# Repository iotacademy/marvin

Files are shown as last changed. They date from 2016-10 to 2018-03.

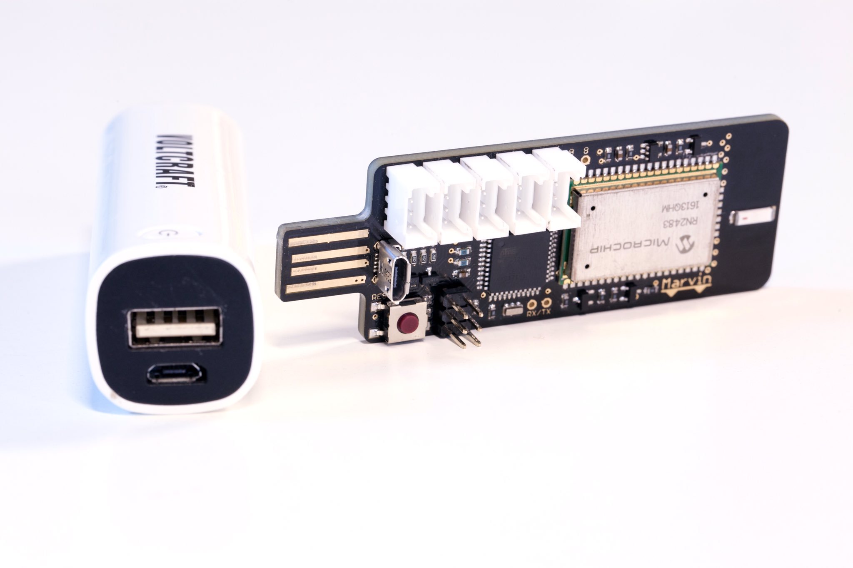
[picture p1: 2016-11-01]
Hardware/Pictures/Marvin_white.jpg

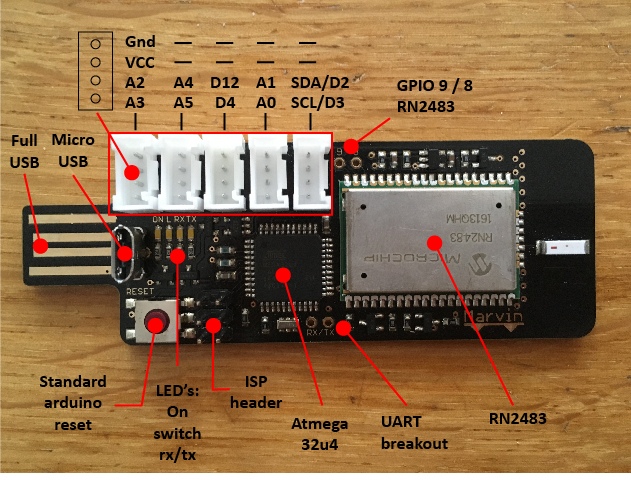
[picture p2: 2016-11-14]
Software/Pictures/Pinout.jpg

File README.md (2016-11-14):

# Marvin

##Hi!!!!

Hello there! Cool of you to made your way here! The whole Marvin team is very excited and welcomes everyone (including you!) to join us in developing awesome/funny/usefull/insightfull or complete bonkers useless gadgets in the world of IoT.

Marvin

##About Marvin

Marvin is easy to use, Arduino based, plug and play grove sensor compatible and works with LoRa communication on the KPN nation covering LoRa network.

Please check our [Kickstarter campaign](https://www.kickstarter.com/projects/688158475/marvin-the-lora-development-board/), the possibilities at the [IoTAcademy](http://iotacademy.nl) and the [RDM Makerspace](http://www.rdmmakerspace.nl/cursussen/internet-of-things).

##What are you doing here?!

Okay that may have come of a bit harsh. We *do* welcome you, but you are kinda on a junction here.

Are you interested in:

[Software](https://github.com/iotacademy/marvin/tree/master/Software)?

or 

[Hardware](https://github.com/iotacademy/marvin/tree/master/Hardware)?

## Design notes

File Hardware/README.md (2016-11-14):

# Marvin Hardware
This overview contains documentation regarding the hardware used in Marvin. 

##General
The Marvin consists of 4 main features: A USB port, Arduino compatible microcontroller, 5 Grove connectors and a LoRa(WAN) modem. The board is optimized to be used for quick and easy applications in R&D and workshops, as well as a very reasonable solution for embedded applications.

##ATMEGA32u4

ATMEGA32u4

##Grove connectors
The 5 grove connectors cover all analog(x3), digital(x1) and I2C(x1). The I2C port can also be used as a digital input/output.

Grove connectors

##ISP
The 2x3 male header is used to burn the bootloader on the microcontroller. As this is done via SPI, this bus is available for other SPI peripherals. On the bottom there are an additional 6 contact pads using pogo pins instead of a 2x3 wired connector.

ISP header

##Serial
The RX/TX pins from the microcontroller are available via an unpopulated connection. The LoRa modem is controlled over the same line, so it needs to be shut down when other UART devices are used to prevent errors.

##GPIO
Next to the Grove connectors there is another two unpopulated connection point, connected to GPIO 8 and 9 of the LoRa module.

GPIO

##Antenna
The antenna is a 868MHz ceramic resonator antenna with a pigtail behind it. The choice to go for a ceramic antenna (instead of the regular antenna on SMA connector that is spec'd) was done for two reasons, the on-pcb ceramic antenna is a lot smaller and less fragile, and in our side-by-side tests the ceramic antenna performed considerably better on all scores.

Antenna

##USB
The full size USB plug and the micro USB are linked directly together. The full size connector is used for plugging it right in your laptop, the micro USB can be used when the unit is embedded in a place where is not easily removeable and makes the system a lot more flexible.

##Level shifters
The microcontroller and the LoRa modem work at different voltages (5v&3.3V), so for the communication and reset lines there are level shifters in place. 

Level Shifters

##Dimensions
The overal dimensions of the PCB are 85x30mm and the pcb is 2.4mm thick. This thickness is required to make the PCB fit the usb port.

Dimensions

##Board and Schematics
See Layout folder.

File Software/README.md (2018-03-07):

# Marvin
Essentials for Marvin LoRa Development

Marvin Plug&Play app: https://dent.mendixcloud.com.
10 week free trial, afterwards free use on demand

Hookup guide: http://www.dentgalaxy.com/marvin/resources-nl/

Enjoy!

## Getting started

### Install Arduino IDE

Download the [Arduino IDE](https://www.arduino.cc/en/Main/Software) and follow the installer. 

If you want to donate to Arduino -to help developing their software we are thankfully using- this is possible, but not mandatory.

### Connect Marvin to computer

Use your left or right (or a combination) hand to push the Marvin in the USB port of your computer. Your computer will quickly befriend it and say "blingBLING", which is computer language for "we are now BFFs!".

Plugged in

### Upload Blinky

Download (or copy-paste the contents of) [Blinky.ino](https://github.com/iotacademy/marvin/blob/master/Software/MarvinBlink/MarvinBlink.ino) and open it in the Arduino IDE.

From the 'Tools' menu select 'Arduino Leonardo' in the 'Boards' section.

Click upload to send the software to the Marvin. If all went well it will say Uploading complete and the second LED will blink, if not try uploading again.

Board selection

Upload sketch

### Check RN2483

Download [MarvinMultiSerial.ino](https://github.com/iotacademy/marvin/blob/master/Software/MarvinMultiSerial/MarvinMultiSerial.ino) and open it in the Arduino IDE.

Upload it to the Marvin and then open the Serial Monitor

Serial Monitor

Set the baudrate to 57600 (same as in the sketch) and select 'CR+NL'. Now you can directly speak to the RN2483 and get a response.

If you for instance send 'sys get ver', the module will return its firmware version back. This will be 1.0.1 with some historic date.

Possible other commands can be find in the module [data sheet](http://ww1.microchip.com/downloads/en/DeviceDoc/40001784E.pdf) or in [one of the many](https://www.disk91.com/2015/technology/networks/first-step-in-lora-land-microchip-rn2483-test/) [examples](https://thinginnovations.uk/getting-started-with-microchip-rn2483-lorawan-modules) [by others](http://kotahi.net/configure-microchip-rn2483-module/).

## Using your first sensor

The Marvin uses Grove sensors. Grove is a standard developed by [Seeedstudio](https://www.seeedstudio.com/category/Grove-c-45.html), a large electronics shop. In their [wiki page](http://wiki.seeedstudio.com/wiki/Main_Page) you can find a quite comprehensive collection of documentation of all products.

### Sensor and connector

The pinout of the Marvin allows for 3 analog sensors, 1 digital and 1 I2C sensor (I2C can also be used as regular digital port). If needed, with a splitter up to 256 I2C can be hooked up though.

Pinout

## Sending message to other Marvin

Upload MarvinMultiSerial to two Marvins

### Listening

On the first Marvin, open serial monitor and type:
```
mac pause 
radio rx 0
```
This will put it in continous listening mode. If it says 'radio_err' it is timed out or received something weird. No worries, just repeat 'radio rx 0' command to restart it.

### Broadcasting

On the second Marvin type:
```
mac pause
radio set pwr 14
radio tx 12345678
```
On the serial monitor of Marvin 1 it should display your message '12345678'.

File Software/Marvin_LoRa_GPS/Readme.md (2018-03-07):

# SETUP YOUR MARVIN + GPS 

## General
The Microchip lora module is connected over UART with the Arduino Leonardo 32u4. Power consumption of the GPS module is around 150 mA.

## Kill power to RN2483
Uart can only handle one master and one slave device. Since GPS is also using UART communcication, you have to kill the power to the RN2483. Do this by writing pin 5 (power RN2483) and pin 6 (reset RN2483) LOW. 

## Connect rx tx pins
Next you connect rx to tx of the gps and tx to rx, using the pads provided on the lower edge of the Marvin (USB pointing to left)

## Use a transistor
To control the power to the GPS, you need an PNP transistor that has the gate connected to one of the arduino's digital pin. 
In active mode, the GPS requires +50mA, which is more then a digital pin of the 32u4 can provide. 
Using a PNP between the VCC of the gps and the VCC of the marvin will allow for enough power to run the gps properly. 
You can use digital pin 12 for this, 3rd grove connector - look on the bottom of the board - to cut off the power. 

In this way, you can retreive gps coordinates, store them in a variable, kill gps power, fire up lora and send variables in the payload. 

Enjoy your gps lora tracker!

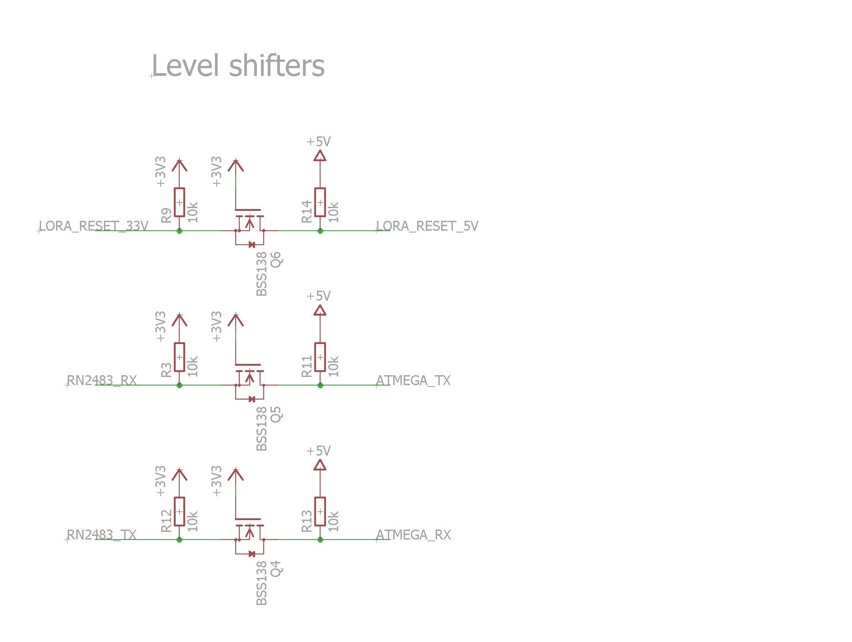
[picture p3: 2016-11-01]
Hardware/Pictures/LevelShifters.JPG

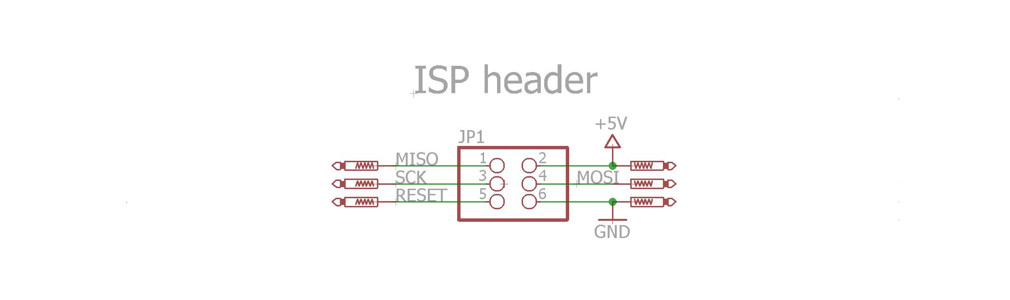
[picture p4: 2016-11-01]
Hardware/Pictures/ISPheader.JPG

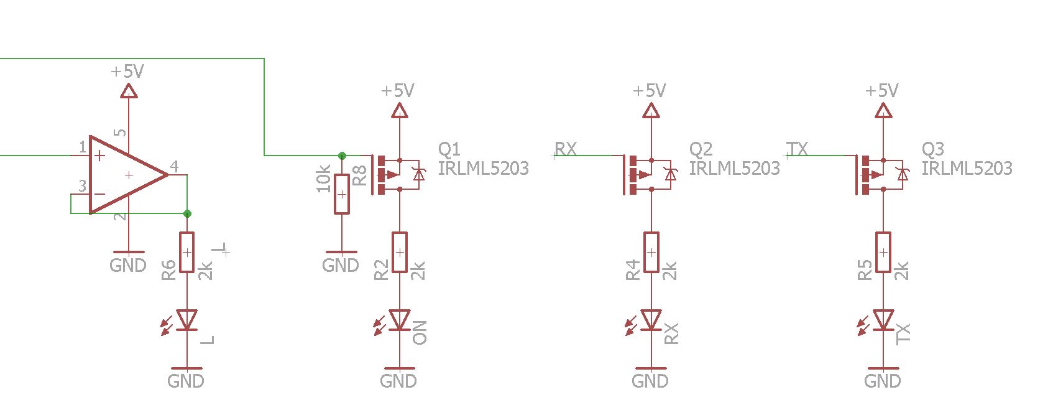
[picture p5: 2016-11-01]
Hardware/Pictures/LEDs.JPG

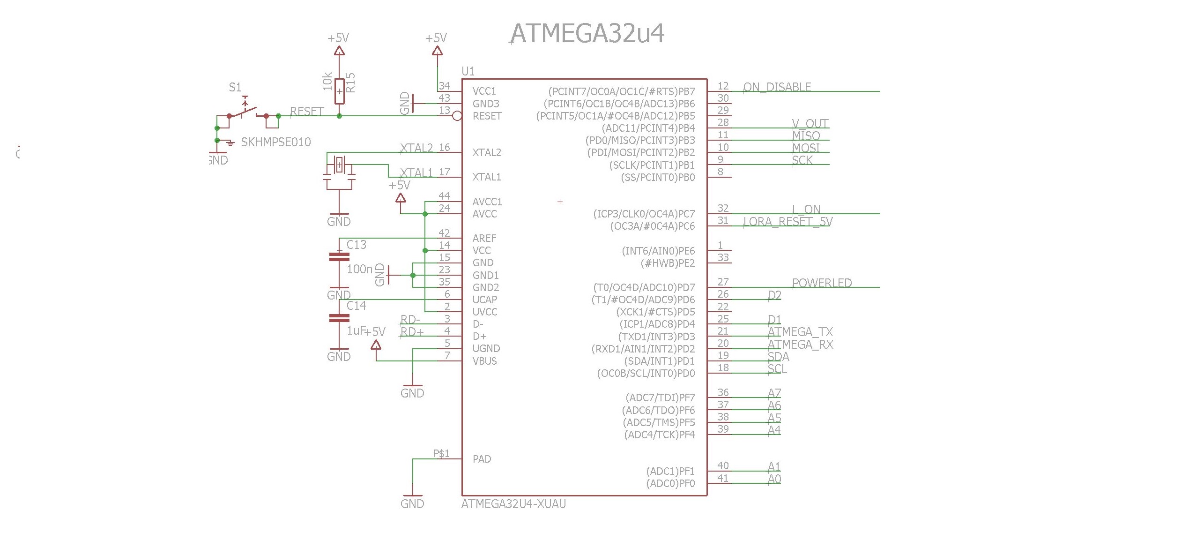
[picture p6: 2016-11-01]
Hardware/Pictures/ATMEGA32u4.JPG

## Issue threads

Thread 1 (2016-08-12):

MarvinMultiSerial doesn't work with arduino SDK 1.6.10

peer23peer, 2016-08-12:

MichielJol, 2016-09-09:
This seems to be true, solution is using Arduino SDK 1.6.9 or 1.6.11

Closed 2016-09-09.

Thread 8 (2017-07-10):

LoRa Arduino UNO

Tonibco, 2017-07-10:
Hi, I would just like to modify Temperature and humidity sketch in order to be able to use it by Arduino 'UNO' Board and LoRa module, rather than 'Mega' one. Since I saw Serial1 port communication is used on this code. So, my question is;

- Which steps should I take in order to modify the code for the purpose I comment above?

Many thanks

overlord1123, 2017-08-04:
I would recommend looking at the wiring in the hardware section. Use Eagle for convenience which is free to download. The hard part is the digital level shifters since Arduino runs on 5V and the module runs at 3.3V.

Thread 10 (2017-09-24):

Seeed GPS Grove Module v1.2 and Marvin

patmolloy, 2017-09-24:
Hi,

I am trying to use this module on the 3rd Marvin Grove Port (Marked D12 and D4 on the bottom of the PCB) in conjunction with the SoftwareSerial library. Here is the start of the sketch. It does not work - SoftSerial.available() always return 0. I have tried swapping the 12,4 around just in case I had RX/TX swapped. In looking at the schematics I am wondering whether that Grove port is really Digital 12 and Digital 4 ?? (seems to suggest D1 and D2).

Assuming I can get the ports right, should this actually work? I cannot see why not!

If I need to use the broken out RX/TX pads on the PCB .. what is the code I need?

Thanks!!

Pat

```
#include <SoftwareSerial.h>
SoftwareSerial SoftSerial(12,4);            // RX, TX
unsigned char buffer[64];                   // buffer array for data receive over serial port
int count=0;                                // counter for buffer array
void setup()
{
    SoftSerial.begin(9600);                 // the SoftSerial baud rate
    Serial.begin(9600);                     // the Serial port of Arduino baud rate.

}

void loop()
{
    Serial.print("Hello --- ");
    Serial.println(SoftSerial.available());
    if (SoftSerial.available())                     // if data is coming from software serial port ==> data is coming from SoftSerial shield
```

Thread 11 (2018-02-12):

Low power mode

ehtick, 2018-02-12:
Can't get the low power mode from the atmega in combination with the RN2483 to work.

I want to create a sampling application which samples at a frequency of 15 minutes.
For this we put the atmega to sleep which works but combined with the RN2483 sys sleep ......  gives hangup's.

What is the correct way to use as little of power possible (SLEEP_MODE_IDLE) in combination with the RN2482 sys sleep command. Now i created a watchdog timer to wakeup again.

ISR(WDT_vect)
{
  sleep_count ++; // keep track of how many sleep cycles
                  // have been completed.
  if (sleep_count == sleep_total)
    Wakeup();          
}

in loop i test that Wakeup has set the volatile int to do action and then sample the data send it and got to sleep again.  Any help is welcome 👍

OlegSomov, 2018-03-08:
Hello @ehtick ,

Is that is what you're looking for? powerDown turns off everything is possible:
```
void loop() {
    LowPower.powerDown(SLEEP_8S, ADC_OFF, BOD_OFF);
    LowPower.powerDown(SLEEP_8S, ADC_OFF, BOD_OFF);

    // Executing some code sending a message.
}
```

ehtick, 2018-03-09:
We use the Lowpower but this does not sleep the RN2483 chip. So after using the LowPower library it still uses about 5-7 mA and this is tho much.

OlegSomov, 2018-03-09:
I just tried to add mac sleep command, and got as low as  1.5-2 mA.. Device is transmitting frames as it supposed to.
```
void loop() {
    send_LoRa_Command("sys sleep 13000");
    LowPower.powerDown(SLEEP_8S, ADC_OFF, BOD_OFF);
    LowPower.powerDown(SLEEP_8S, ADC_OFF, BOD_OFF);

    // Executing some code sending a message.
}
```

Is your device stops transmitting?

ehtick, 2018-03-09:
Yes it stops, engineer at microchip give the advise to set a delay of 150ms after sending 'sys sleep xxxx'

OlegSomov, 2018-03-09:
Hmm.. even without delay I have module working and transmitting constantly combining powerDown and "sys sleep xxxxx". Couple of questions for you:
1. How do you check the transmissions?(if device transmitted or not)
2. Where is device connected to, when you running a code with sleep and powerdown?
3. Do you have any prints to USB serial?

ehtick, 2018-03-09:
1 we always expect a result from the RN2483 so sometimes 'ok', 'accepted'
when sending payload wait for mac_tx_ok. Problem with the sys sleep command is that it sends ok when it wakes up again.
2 We do not run code on powerdown or sleep
3 usb is deactivated and no serial print is used (when debugging yes :))

Updated the firmware for the RN2483 to the latest one, microchip advise, but this does not help.

OlegSomov, 2018-03-09:
1. After the powerDown most of the board peripherals shut down, so you not going to see anything in the debugging port, so when you use powerDown, to check transmission please check the Network Server side.

What is the value you put in "sys sleep ..."?

ehtick, 2018-03-12:
20 minutes so 20 * 60 * 1000 (long)

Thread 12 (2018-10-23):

Marvin LoRa stops after first loop when code WaterFlowSensor is changed with code TemperatureSensor

PannekoekenMetSpinazie, 2018-10-23:
Hi Githubbers,

Today I tried to connect Marvin LoRa device with The Things Network, fortunaly with basic program from https://github.com/iotacademy/marvin/blob/master/Software/MarvinBase/MarvinBase.ino allows me to connect to The Things Network (Keys are changed to the ones I use with TTN).

After I changed the code with temperature sensor to waterflow sensor the code stops running after the first loop. The first reading is send to TTN, but not the following readings because the loop got stuck.

Waterflow sensor is YF-402.
The port used is farthest from the Marvin LoRa USB.
Program: Arduino
Board: Arduino Leonardo

Can you guys explain what has happened to the loops?
The code I use is as follows:

/*
MarvinBase

Basic controls of IoT Academy Marvin LoRa Development board.

This version supports:

Sending LoRa uplink messages using ABP
Blink three times when sending data
Power control to RN2483 module
Instructions:

Get the latest version of the Arduino software
In Arduino IDE select Arduino Leonardo and com port of your device
Please adjust ABP adresses and key below to match yours
The loop() is where the actual stuff happens. Adjust input of send_lora_data() in void loop() to send your own data.
*/
/// #include <CayenneLPP.h> //App integratie

/// CayenneLPP lpp(51); //Buffergrootte in bytes

// Port to assign the type of lora data (any port can be used between 1 and 223)
int set_port = 1;

// Some standard ports that depend on the layout of the Marvin
long defaultBaudRate = 57600;
int reset_port = 5;
int RN2483_power_port = 6; //Note that an earlier version of the Marvin doesn't support seperate power to RN2483
int led_port = 13;

int flowPin = 39; //This is the input pin on the Arduino
float flowRate; //This is the value we intend to calculate.
volatile float count; //This integer needs to be set as volatile to ensure it updates correctly during the interrupt process.

//*** Set parameters here BEGIN ---->
String set_nwkskey = "XXXXXXXXXXXXXXXXXXXXXXXXXXXXXX"; // Make sure you use your keys from TTN here
String set_appskey = "XXXXXXXXXXXXXXXXXXXXXXXXXXXXXX";
String set_devaddr = "XXXXXXXX";
//*** <---- END Set parameters here

/*

Setup() function is called when board is started. Marvin uses a serial connection to talk to your pc and a serial

connection to talk to the RN2483, these are both initialized in seperate functions. Also some Arduino port are

initialized and a LED is called to blink when everything is done.
*/
void setup() {
Serial.begin(defaultBaudRate);
Serial1.begin(defaultBaudRate);
InitializeSerials(defaultBaudRate);
initializeRN2483(RN2483_power_port, reset_port);
pinMode(led_port, OUTPUT); // Initialize LED port
blinky();

pinMode(flowPin, INPUT); //Sets the pin as an input
attachInterrupt(0, Flow, RISING); //Configures interrupt 0 (pin 2 on the Arduino Uno) to run the function "Flow"
Serial.begin(9600); //Start Serial
}

void loop() {

count = 0; // Reset the counter so we start counting from 0 again
interrupts(); //Enables interrupts on the Arduino
delay (1000); //Wait 1 second
noInterrupts(); //Disable the interrupts on the Arduino

//Start the math
flowRate = (count / 4.380); //Take counted pulses in the last second and multiply by 98
flowRate = flowRate * 60; //Convert seconds to minutes, giving you mL / Minute

flowRate = flowRate + 0.5;
int mL_min = (int)flowRate;

Serial.println(mL_min);

delay(100);
send_LoRa_data(set_port, String(mL_min));
blinky();
delay(1000);
read_data_from_LoRa_Mod();
delay(3000);
}

void Flow()
{
count++; //Every time this function is called, increment "count" by 1
}

void InitializeSerials(int baudrate)
{
delay(1000);
print_to_console("Serial ports initialised");
}

void initializeRN2483(int pwr_port, int rst_port)
{
//Enable power to the RN2483
pinMode(pwr_port, OUTPUT);
digitalWrite(pwr_port, HIGH);
print_to_console("RN2483 Powered up");
delay(1000);

//Disable reset pin
pinMode(rst_port, OUTPUT);
digitalWrite(rst_port, HIGH);

//Configure LoRa module
send_LoRa_Command("sys reset");
read_data_from_LoRa_Mod();

send_LoRa_Command("radio set crc off");
delay(1000);
read_data_from_LoRa_Mod();

send_LoRa_Command("mac set nwkskey " + set_nwkskey);
read_data_from_LoRa_Mod();

send_LoRa_Command("mac set appskey " + set_appskey);
read_data_from_LoRa_Mod();

send_LoRa_Command("mac set devaddr " + set_devaddr);
read_data_from_LoRa_Mod();

//For this commands some extra delay is needed.
/// send_LoRa_Command("mac set adr on");
/// delay(1000);
/// read_data_from_LoRa_Mod();

send_LoRa_Command("mac save");
delay(1000);
read_data_from_LoRa_Mod();

send_LoRa_Command("mac join abp");
delay(1000);
read_data_from_LoRa_Mod();

}

void print_to_console(String message)
{
Serial.println(message);
}

void read_data_from_LoRa_Mod()
{
if (Serial1.available()) {
String inByte = Serial1.readString();
Serial.println(inByte);
}

}

void send_LoRa_Command(String cmd)
{
print_to_console("Now sending: " + cmd);
Serial1.println(cmd);
delay(500);
}

void send_LoRa_data(int tx_port, String rawdata)
{
send_LoRa_Command("mac tx uncnf " + String(tx_port) + String(" ") + rawdata);
}

void blinky()
{
digitalWrite(led_port, HIGH); // turn the LED on (HIGH is the voltage level)
delay(500); // wait for a second
digitalWrite(led_port, LOW); // turn the LED off by making the voltage LOW
delay(500); // wait for a second
digitalWrite(led_port, HIGH); // turn the LED on (HIGH is the voltage level)
delay(500); // wait for a second
digitalWrite(led_port, LOW); // turn the LED off by making the voltage LOW
delay(500); // wait for a second

}

Closed 2018-10-24.

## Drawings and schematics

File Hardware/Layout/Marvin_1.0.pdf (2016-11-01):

# Level shifters

# SKHMPSE010 ⁺³V3 10k

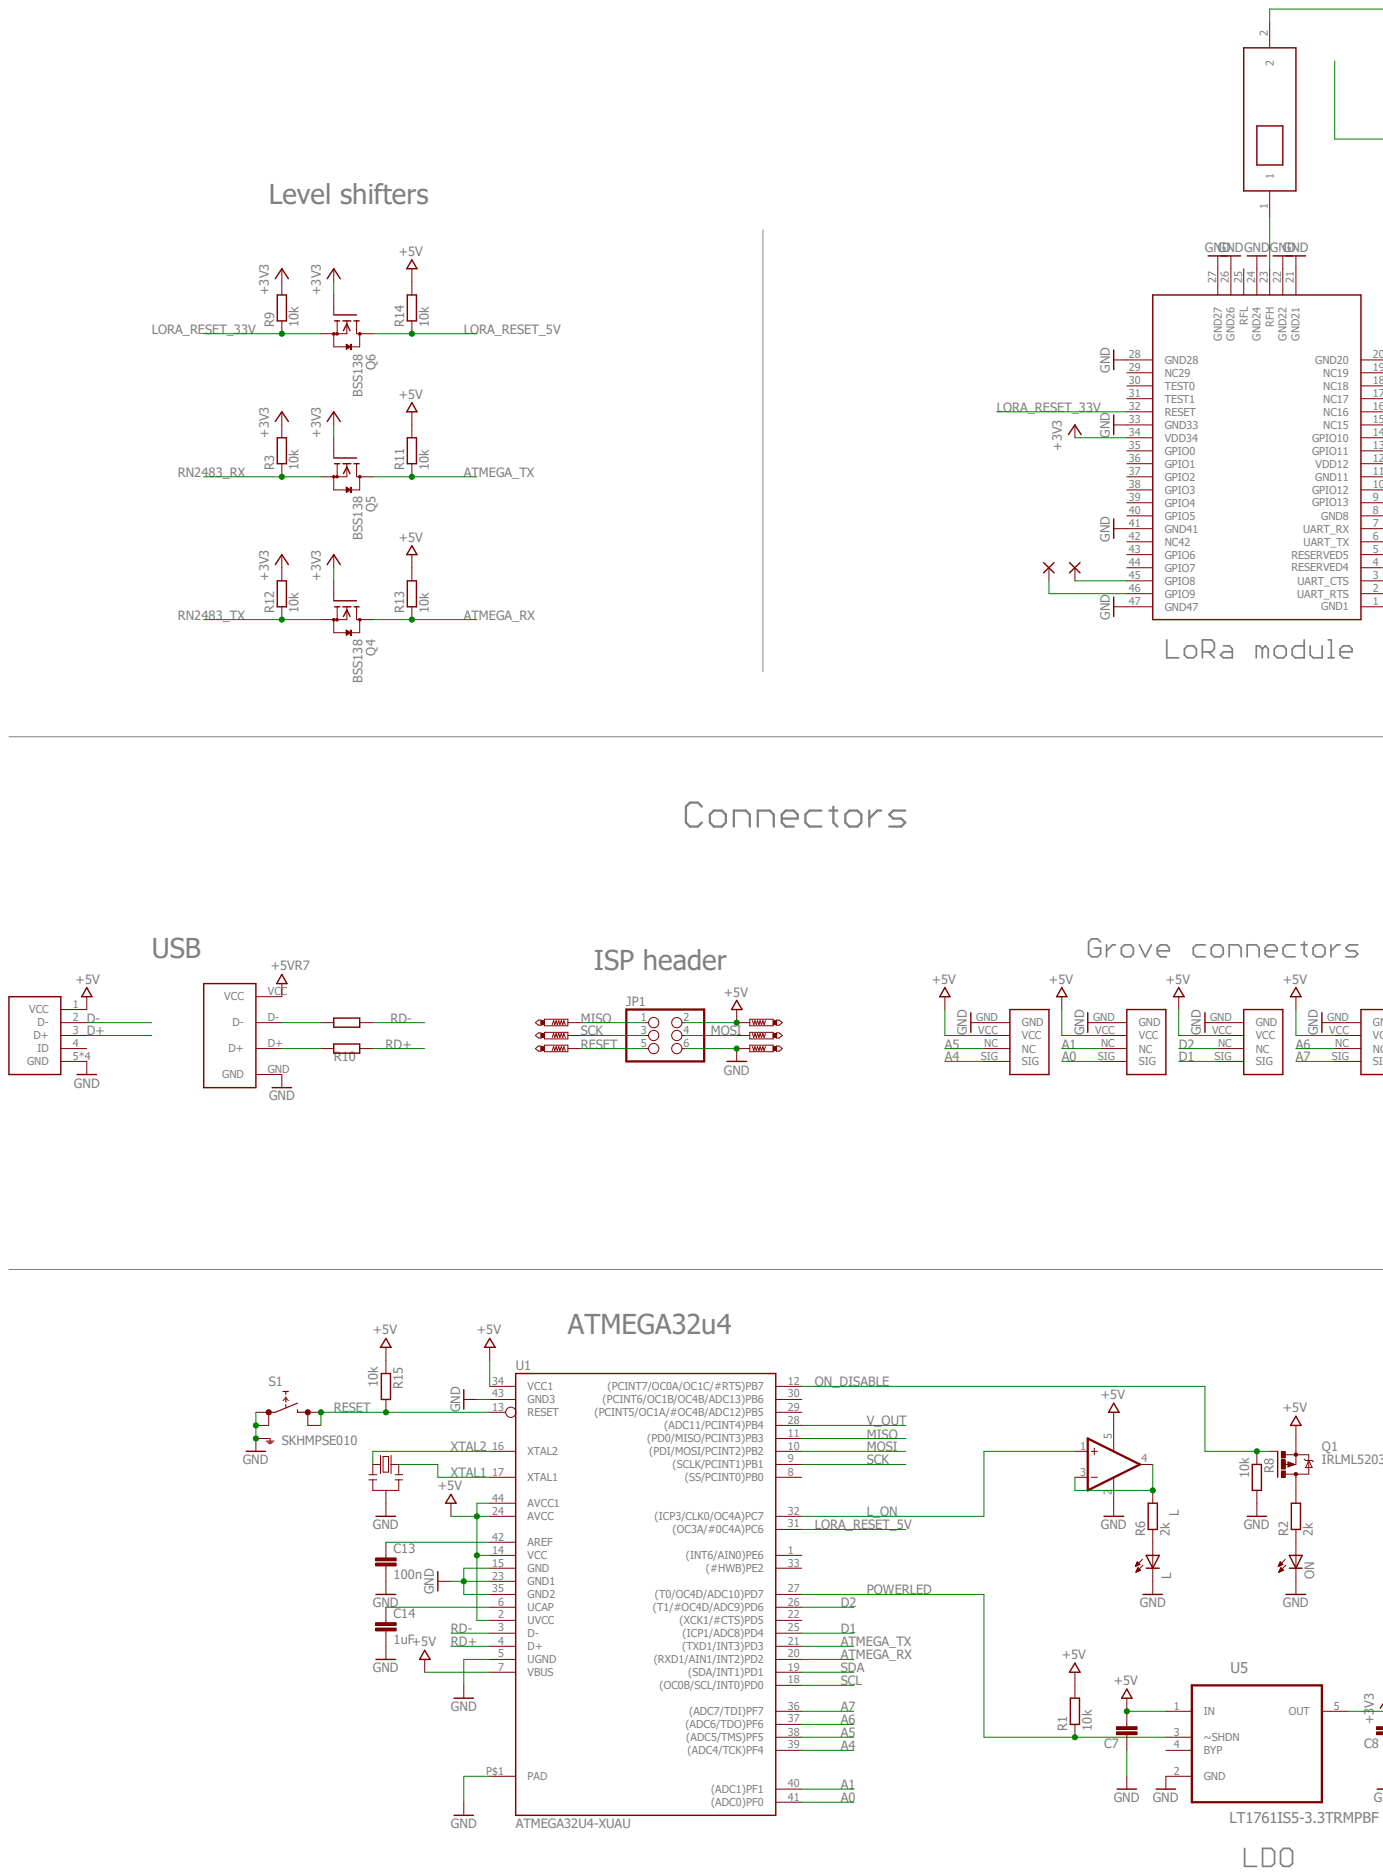
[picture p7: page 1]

VCC 14

GND1 23

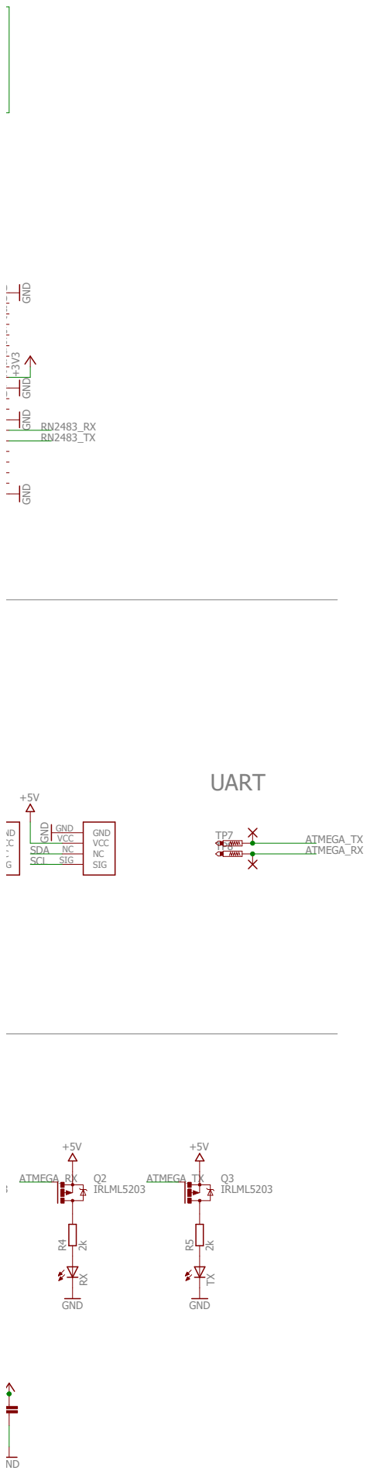
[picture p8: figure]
UART; GND GND GND GND; GND; GND ²k; IRLML5203; VCC VCC; SIG SIG; GND GND; ATMEGA_RX; SDA SCL; ATMEGA_TX

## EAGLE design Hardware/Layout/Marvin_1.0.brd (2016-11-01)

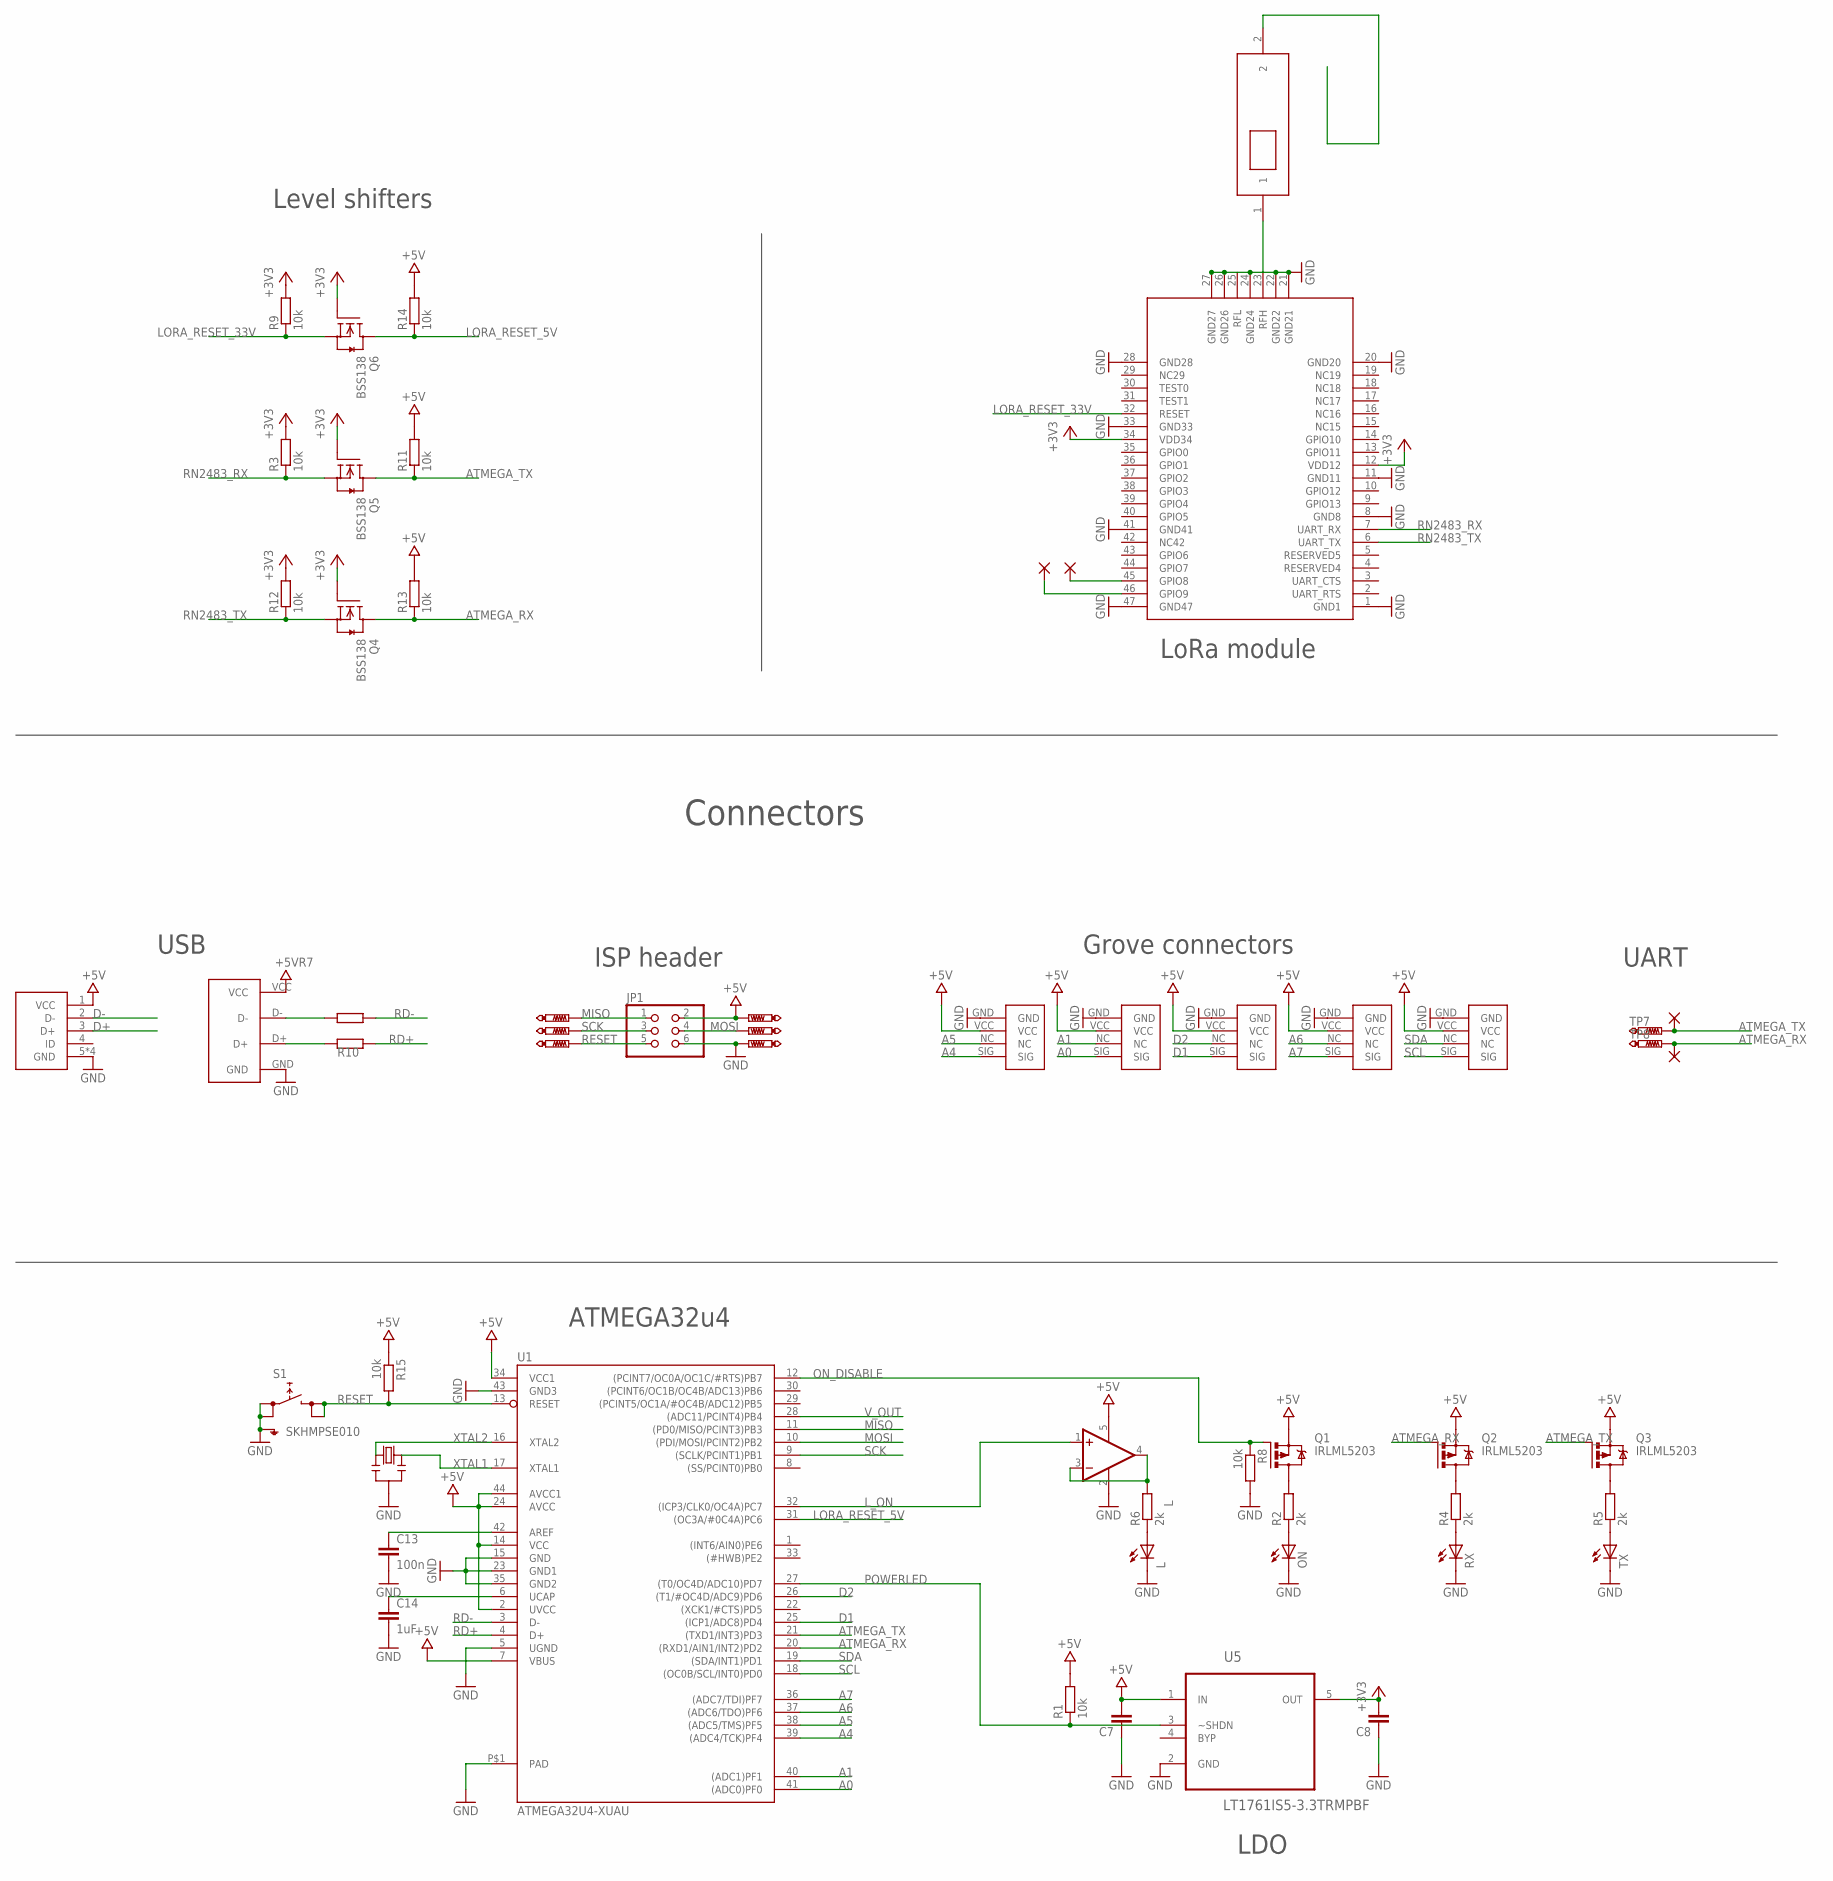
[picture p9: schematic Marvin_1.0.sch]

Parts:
A1, A2, A3: GROVE; 4POS2MM
C7, C8: C-EUC0603; C0603
C13: 100n; C0603K
C14: 1uF; C0603K
D2, D2/I2C: GROVE; 4POS2MM
IC1: LM321MF; SOT23-5
JP1: PINHD-2X3; 2X03
L: LEDSML0603; SML0603
ON: LEDSML0603; SML0603
PAD1, PAD2, PAD3, PAD4: WIREPAD1,6/0,9; 1,6/0,9
Q1, Q2, Q3: IRLML5203; MICRO3
Q4, Q5, Q6: BSS138; SOT23
R1, R3, R8, R9, R11, R12, R13, R14, R15: 10k; R0603
R2, R4, R5, R6: 2k; R0603
R7, R10: 30; R0603-ROUND
RX: LEDSML0603; SML0603
S1: SKHMPSE010; SKHMPXE010
TP1, TP2, TP3, TP4, TP5, TP6, TP7, TP8: PTR1B1,27; B1,27
TX: LEDSML0603; SML0603
U1: ATMEGA32U4-XUAU; TQFP44-PAD
U5: LT1761IS5-3.3TRMPBF; SOT95P280X100-5N
U$1: RN2483
U$3: USBA; USBAPLUG
U$16: USB-VERTICAL; MICROUSBVERTICAL
U$25: 868AT
Y1: CSTCE16M0V53-R0 16MHZ; RESONATOR

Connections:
+3V3: C8.2, Q4.1 (G), Q5.1 (G), Q6.1 (G), R3.2, R9.2, R12.2, U5.5 (OUT), U$1.12 (VDD12), U$1.34 (VDD34)
+5V: A1.VCC, A2.VCC, A3.VCC, C7.2, D2.VCC, D2/I2C.VCC, IC1.5 (V+), JP1.2, Q1.2 (S), Q2.2 (S), Q3.2 (S), R1.2, R11.2, R13.2, R14.2, R15.1, TP6.TP, U1.2 (UVCC), U1.7 (VBUS), U1.14 (VCC), U1.24 (AVCC), U1.34 (VCC1), U1.44 (AVCC1), U5.1 (IN), U$3.VCC, U$16.1 (VCC)
A0: A1.SIG, U1.41 ((ADC0)PF0)
A1: A1.NC, U1.40 ((ADC1)PF1)
A4: A2.SIG, U1.39 ((ADC4/TCK)PF4)
A5: A2.NC, U1.38 ((ADC5/TMS)PF5)
A6: A3.NC, U1.37 ((ADC6/TDO)PF6)
A7: A3.SIG, U1.36 ((ADC7/TDI)PF7)
AREF1: C13.1, U1.42 (AREF)
ATMEGA_RX: PAD2.1, Q2.1 (G), Q4.3 (D), R13.1, TP8.TP, U1.20 ((RXD1/AIN1/INT2)PD2)
ATMEGA_TX: PAD1.1, Q3.1 (G), Q5.3 (D), R11.1, TP7.TP, U1.21 ((TXD1/INT3)PD3)
D1: D2.SIG, U1.25 ((ICP1/ADC8)PD4)
D2: D2.NC, U1.26 ((T1/#OC4D/ADC9)PD6)
D+: R10.2, U$3.D+, U$16.3 (D+)
D-: R7.2, U$3.D-, U$16.2 (D-)
GND: A1.GND, A2.GND, A3.GND, C7.1, C8.1, C13.2, C14.2, D2.GND, D2/I2C.GND, IC1.2 (V-), JP1.6, L.C, ON.C, R8.2, RX.C, S1.1 (1.1), S1.2 (1.2), S1.5 (SH), TP4.TP, TX.C, U1.5 (UGND), U1.15 (GND), U1.23 (GND1), U1.35 (GND2), U1.43 (GND3), U1.P$1 (PAD), U5.2 (GND), U$1.1 (GND1), U$1.8 (GND8), U$1.11 (GND11), U$1.20 (GND20), U$1.21 (GND21), U$1.22 (GND22), U$1.24 (GND24), U$1.26 (GND26), U$1.27 (GND27), U$1.28 (GND28), U$1.33 (GND33), U$1.41 (GND41), U$1.47 (GND47), U$3.GND, U$16.5 (GND), U$16.P$1 (GND), U$16.P$2 (GND), U$16.P$3 (GND), Y1.2
L: IC1.3 (-IN), IC1.4 (OUT), R6.2
LORA_RESET_5V: Q6.3 (D), R14.1, U1.31 ((OC3A/#0C4A)PC6)
LORA_RESET_33V: Q6.2 (S), R9.1, U$1.32 (RESET)
L_ON: IC1.1 (+IN), U1.32 ((ICP3/CLK0/OC4A)PC7)
MISO: JP1.1, TP1.TP, U1.11 ((PD0/MISO/PCINT3)PB3)
MOSI: JP1.4, TP5.TP, U1.10 ((PDI/MOSI/PCINT2)PB2)
unnamed: ON.A, R2.1
unnamed: R4.1, RX.A
unnamed: R5.1, TX.A
unnamed: L.A, R6.1
unnamed: Q1.3 (D), R2.2
unnamed: PAD3.1, U$1.46 (GPIO9)
unnamed: Q2.3 (D), R4.2
unnamed: Q3.3 (D), R5.2
unnamed: PAD4.1, U$1.45 (GPIO8)
ON_DISABLE: Q1.1 (G), R8.1, U1.12 ((PCINT7/OC0A/OC1C/#RTS)PB7)
POWERLED: R1.1, U1.27 ((T0/OC4D/ADC10)PD7), U5.3 (~SHDN)
RD+: R10.1, U1.4 (D+)
RD-: R7.1, U1.3 (D-)
RESET: JP1.5, R15.2, S1.3 (2.1), S1.4 (2.2), TP3.TP, U1.13 (RESET)
RFH: U$1.23 (RFH), U$25.1
RN2483_RX: Q5.2 (S), R3.1, U$1.7 (UART_RX)
RN2483_TX: Q4.2 (S), R12.1, U$1.6 (UART_TX)
SCK: JP1.3, TP2.TP, U1.9 ((SCLK/PCINT1)PB1)
SCL: D2/I2C.SIG, U1.18 ((OC0B/SCL/INT0)PD0)
SDA: D2/I2C.NC, U1.19 ((SDA/INT1)PD1)
UCAP: C14.1, U1.6 (UCAP)
V_OUT: U1.28 ((ADC11/PCINT4)PB4)
XTAL1: U1.17 (XTAL1), Y1.3
XTAL2: U1.16 (XTAL2), Y1.1

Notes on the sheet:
Grove connectors
LoRa module
LDO
USB
Level shifters
ATMEGA32u4
ISP header
UART
Connectors

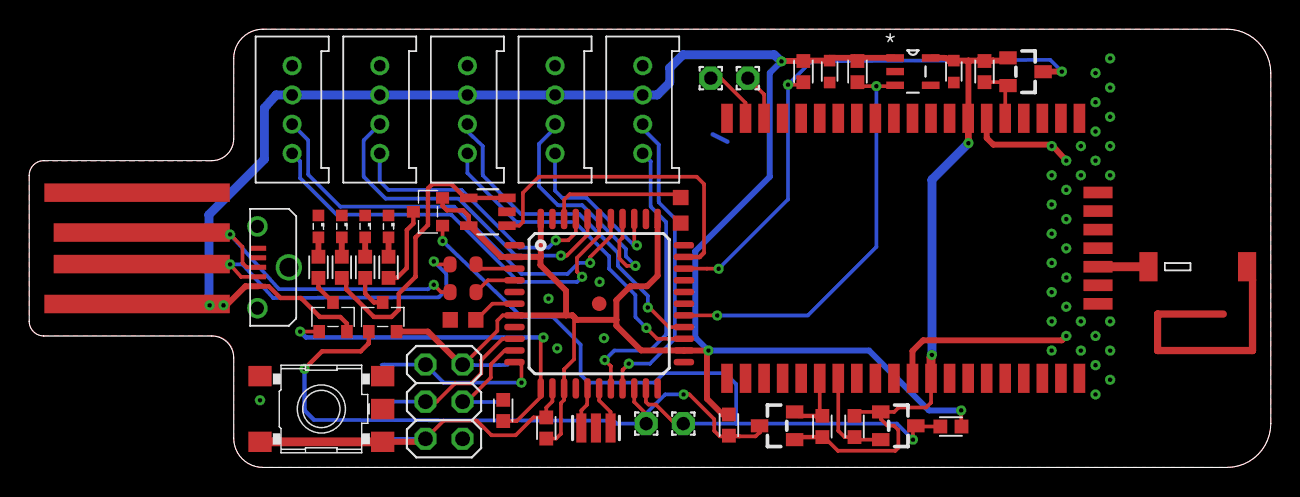
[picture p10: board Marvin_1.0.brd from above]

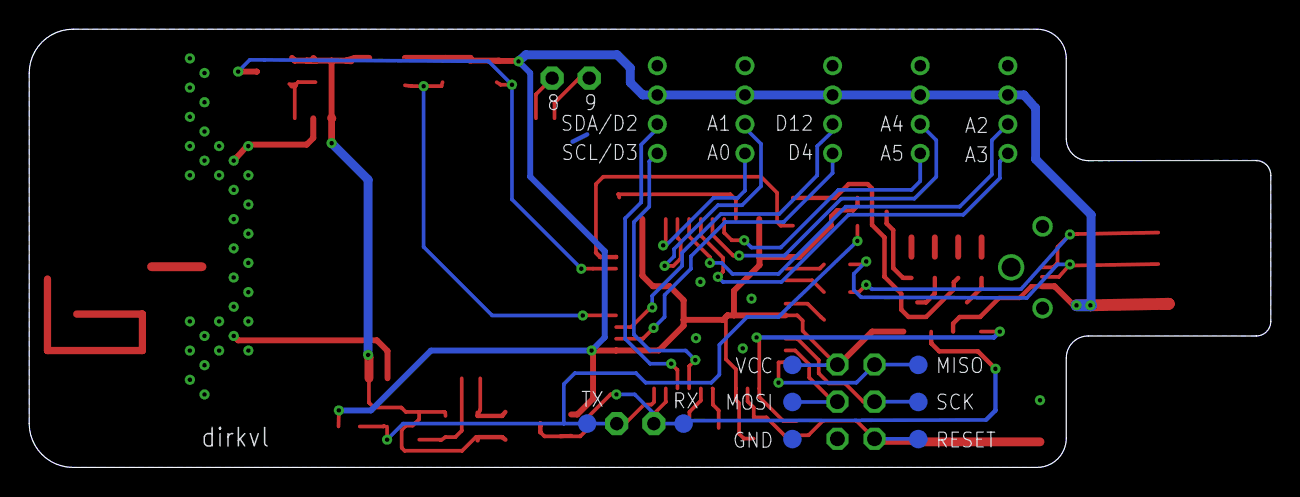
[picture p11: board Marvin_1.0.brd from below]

Board: 2 copper layers, 85.0 x 30.0 mm, 56 parts (8 on the bottom side), 45 nets.

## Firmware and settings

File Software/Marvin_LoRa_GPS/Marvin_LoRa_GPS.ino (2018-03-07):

/*
  Marvin_LoRa_GPS + Button
  
  Connect the gps using a grove - female jumper wire:
  - GND to any GND
  - VCC to Collector pin of PNP transistor
  - RX  to TX - located on the lower edge of the board. 
  - TX to RX - locataed on the lower edge of the board.
  
  For the pnp transistor:
  - Connect Collector pin to VCC GPS
  - Connect Emitter pin to VCC from ISP header
  - Connect gate pin to D12

  This version supports:
  - Sending LoRa uplink messages using ABP that are given as input from the serial port on your laptop
  - Blink three times when sending data
  - Power control to RN2483 module

  Instructions:
  - Get the latest version of the Arduino software
  - In Arduino IDE select Arduino Leonardo and com port of your device
  - Please adjust ABP adresses and key below to match yours
  - Download tinypgs++ library and import it in your arduino IDE: Sketch > Include library > add .zip library
*/
// Port to assign the type of lora data (any port can be used between 1 and 223)
int     set_port  = 1;

// Some standard ports that depend on the layout of the Marvin
long    defaultBaudRate = 9600;
long    newBaudRate = 57600;
int     reset_port = 5;
int     RN2903_power_port = 6;
int     led_port = 13;
int     buttonstate = A3;
int     gps_pwr = 3;
float   latti;
float   longi;
int     counter = 0;
int     powerstategps = 0;
int     waarde;


//*** Set parameters here BEGIN ---->
String  set_nwkskey = "xxxxxxxxxxxxxxxxxxxxxxxxxxxxxxxx"; // Put your 32 hex char here
String  set_appskey = "xxxxxxxxxxxxxxxxxxxxxxxxxxxxxxxx"; // Put your 32 hex char here
String  set_devaddr = "xxxxxxxx"; // Put your 8 hex char here
//*** <---- END Set parameters here

// Some global items
String reader = "";
#include <TinyGPS++.h>  //you will have to download+install the tinygps++ library, just google it, first hit.
#include <math.h>
TinyGPSPlus gps;


void setup()
{
  pinMode(gps_pwr, OUTPUT);
  pinMode(buttonstate, INPUT);
  digitalWrite(gps_pwr, LOW);
  initializeRN2903(RN2903_power_port, reset_port);
  delay(100);
  Serial.println("Hello There, Let's go!");
  pinMode(led_port, OUTPUT); // Initialize LED port
  blinky();
}

void loop(){

// This program assumes you use a button on the A3 port. Each button press the program below will run. 

  if (digitalRead(buttonstate) == 1 && powerstategps == 0){
      restartRN2903(RN2903_power_port, reset_port);
      send_LoRa_Command("mac tx uncnf " + String(set_port) + String(" ") + 01);                 //send confirmation message
      delay(1000);
      read_data_from_LoRa_Mod();
      blinky();
      delay(1000);
      Serial.println("Zeroing in on your location, just a sec...");      //start gps tracking
      killRN2903(RN2903_power_port, reset_port);                                                //kill rn module for uart
      delay(100);
      digitalWrite(gps_pwr, HIGH);                                                              //start gps on port gps_pwr
      powerstategps = 1;                                                                        //write variable to indicate gps is on
      print_to_console("GPS Powered up");
  }
  
   if (digitalRead(buttonstate) == 1 && powerstategps == 1){
      digitalWrite(gps_pwr, LOW);
      print_to_console("GPS Killed!");
      powerstategps = 0;
      delay(2000);
   }
  
  if (digitalRead(gps_pwr) == HIGH){
        printFloat(gps.location.lat(), gps.location.isValid(), 11, 6);                        //start printing values - will return stars as long as there is no valid location
        printFloat(gps.location.lng(), gps.location.isValid(), 12, 6);
        Serial.println(" ");
        smartDelay(1000);

        if (millis() > 5000 && gps.charsProcessed() < 10) {
            Serial.println(F("No GPS data received: check wiring"));
            blinky_error();
        }
  
        if(gps.location.isValid() == true && gps.location.isUpdated() == true){
                    digitalWrite(13, HIGH);

                    latti = gps.location.lat();
                    longi = gps.location.lng();        
                    uint32_t  n = latti * 1000000;
                    uint32_t  e = longi * 1000000;
                    Serial.println(n);
                    Serial.println(e);  
                    blinky_error();
                    digitalWrite(gps_pwr, LOW); //kill gps
                    powerstategps = 0;
                    Serial.println("GPS KILLED");
                    Serial.println("sending gps now");
                    
                    restartRN2903(RN2903_power_port, reset_port);
                    digitalWrite(led_port, HIGH);
                    send_LoRa_Command("mac tx uncnf " + String(set_port) + String(" ") + String(n) + String(e));
                    delay(1000);
                    read_data_from_LoRa_Mod();
                    blinky();
                    delay(1000);
                    killRN2903(RN2903_power_port, reset_port);
                    digitalWrite(led_port, LOW);
                    
        }
    }
// go back to main loop again and wait for gps to become true
}


//Lora part --------------------------------------------

void InitializeSerials(long baudrate)
{
  Serial.flush ();   // wait for send buffer to empty
  delay (100);    // let last character be sent
  Serial1.flush ();   // wait for send buffer to empty
  delay (100);    // let last character be sent
  Serial.end ();
  Serial1.end ();
  delay(100);
  Serial.begin(baudrate);
  Serial1.begin(baudrate);
  delay(100);
  print_to_console("Serial ports initialised");
}

void initializeRN2903(int pwr_port, int rst_port)
{
  //Enable power to the RN2903
  InitializeSerials(newBaudRate);
  delay(1000);
  pinMode(pwr_port, OUTPUT);
  digitalWrite(pwr_port, HIGH);
  delay(1000);
  print_to_console("RN2903 Powered up");

  //Disable reset pin
  pinMode(rst_port, OUTPUT);
  digitalWrite(rst_port, HIGH);

  //Configure LoRa module
  send_LoRa_Command("sys reset");
  read_data_from_LoRa_Mod();

  send_LoRa_Command("mac set nwkskey " + set_nwkskey);
  read_data_from_LoRa_Mod();

  send_LoRa_Command("mac set appskey " + set_appskey);
  read_data_from_LoRa_Mod();

  send_LoRa_Command("mac set devaddr " + set_devaddr);
  read_data_from_LoRa_Mod();

  //For this commands some extra delay is needed.
  send_LoRa_Command("mac set adr on");
  //send_LoRa_Command("mac set dr 0"); //uncomment this line to fix the RN2903 on SF12 (dr=DataRate)
  read_data_from_LoRa_Mod();

  send_LoRa_Command("mac save");
  delay(1000);
  read_data_from_LoRa_Mod();

}

void killRN2903(int pwr_port, int rst_port)
{
  //disable power to the RN2903
 // pinMode(pwr_port, OUTPUT);
 // digitalWrite(pwr_port, LOW);
  //Disable reset pin
  pinMode(rst_port, OUTPUT);
  digitalWrite(rst_port, LOW);
  print_to_console("RN2903 killed");
  delay(1000);
  InitializeSerials(defaultBaudRate);
}

void restartRN2903(int pwr_port, int rst_port)
{
  //Enable power to the RN2903
  InitializeSerials(newBaudRate);
  delay(1000);
  //Disable reset pin
  pinMode(rst_port, OUTPUT);
  digitalWrite(rst_port, HIGH);
  pinMode(pwr_port, OUTPUT);
  digitalWrite(pwr_port, HIGH);
  delay(1000);
  print_to_console("RN2903 repowered up");
  
  send_LoRa_Command("mac join abp");
  delay(1000);
  read_data_from_LoRa_Mod();
  send_LoRa_Command("radio set crc off");
  delay(1000);
  read_data_from_LoRa_Mod();
  delay(100);
}

void print_to_console(String message)
{
  Serial.println(message);
}

void read_data_from_LoRa_Mod()
{
  if (Serial1.available()) {
    String inByte = Serial1.readString();
    delay(100);
    Serial.println(inByte);
  }

}

void send_LoRa_Command(String cmd)
{
  print_to_console("Now sending: " + cmd);
  Serial1.println(cmd);
  delay(500);
}

void send_LoRa_data(int tx_port, String rawdata)
{
  send_LoRa_Command("mac tx uncnf " + String(tx_port) + String(" ") + rawdata);
  delay(100);
}


void blinky()
{
  digitalWrite(led_port, HIGH);   // turn the LED on (HIGH is the voltage level)
  delay(500);              // wait for a second
  digitalWrite(led_port, LOW);    // turn the LED off by making the voltage LOW
  delay(500);              // wait for a second
  digitalWrite(led_port, HIGH);   // turn the LED on (HIGH is the voltage level)
  delay(500);              // wait for a second
  digitalWrite(led_port, LOW);    // turn the LED off by making the voltage LOW
  delay(500);              // wait for a second

}
void blinky_error()
{
  digitalWrite(led_port, HIGH);   // turn the LED on (HIGH is the voltage level)
  delay(50);              // wait for a second
  digitalWrite(led_port, LOW);    // turn the LED off by making the voltage LOW
  delay(50);              // wait for a second
  digitalWrite(led_port, HIGH);   // turn the LED on (HIGH is the voltage level)
  delay(50);              // wait for a second
  digitalWrite(led_port, LOW);    // turn the LED off by making the voltage LOW
  delay(50);              // wait for a second
  digitalWrite(led_port, HIGH);   // turn the LED on (HIGH is the voltage level)
  delay(50);              // wait for a second
  digitalWrite(led_port, LOW);    // turn the LED off by making the voltage LOW
  delay(50);              // wait for a second
  digitalWrite(led_port, HIGH);   // turn the LED on (HIGH is the voltage level)
  delay(50);              // wait for a second
  digitalWrite(led_port, LOW);    // turn the LED off by making the voltage LOW
  delay(50);              // wait for a second

}
//---------------------end lora part

// This custom version of delay() ensures that the gps object
// is being "fed".
static void smartDelay(unsigned long ms)
{
  unsigned long start = millis();
  do
  {
    while (Serial1.available())
      gps.encode(Serial1.read());
  } while (millis() - start < ms);
}

static void printFloat(float val, bool valid, int len, int prec)
{
  if (!valid)
  {
    while (len-- > 1)
      Serial.print('*');
    Serial.print(' ');
  }
  else
  {
    Serial.print(val, prec);
    int vi = abs((int)val);
    int flen = prec + (val < 0.0 ? 2 : 1); // . and -
    flen += vi >= 1000 ? 4 : vi >= 100 ? 3 : vi >= 10 ? 2 : 1;
    for (int i = flen; i < len; ++i)
      Serial.print(' ');
  }
  smartDelay(0);
}

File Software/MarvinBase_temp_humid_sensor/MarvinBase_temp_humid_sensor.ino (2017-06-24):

/*
MarvinBase

Basic controls of IoT Academy Marvin LoRa Development board.

This version supports:
	- Sending LoRa uplink messages using ABP 
	- Blink three times when sending data
  - Power control to RN2483 module

Instructions:
	- Get the latest version of the Arduino software
	- In Arduino IDE select Arduino Leonardo and com port of your device
	- Please adjust ABP adresses and key below to match yours
	- The loop() is where the actual stuff happens. Adjust input of send_lora_data() in void loop() to send your own data.
*/
// Port to assign the type of lora data (any port can be used between 1 and 223)
int     set_port  = 1;

// Some standard ports that depend on the layout of the Marvin
long    defaultBaudRate = 57600;
int     reset_port = 5;
int     RN2483_power_port = 6; //Note that an earlier version of the Marvin doesn't support seperate power to RN2483
int     led_port = 13;

//*** Set parameters here BEGIN ---->
String  set_nwkskey = "00000000000000000000000000000000";
String  set_appskey = "00000000000000000000000000000000";
String  set_devaddr = "00000000";
//*** <---- END Set parameters here

//** Set thigs right for the Grove temperature / humidity sensor
#include "DHT.h"      //download it here: https://github.com/Seeed-Studio/Grove_Temperature_And_Humidity_Sensor
                      // press clone/download and then download as .zip
                      
#define DHTPIN A3     // A3 is closes to the usb port of Marvin

// define the type of sensor used (there are others)
#define DHTTYPE DHT11   // DHT 11 

DHT dht(DHTPIN, DHTTYPE);

/*
 * Setup() function is called when board is started. Marvin uses a serial connection to talk to your pc and a serial
 * connection to talk to the RN2483, these are both initialized in seperate functions. Also some Arduino port are 
 * initialized and a LED is called to blink when everything is done. 
 */
void setup() {

  Serial.begin(defaultBaudRate);
  Serial1.begin(defaultBaudRate);
  InitializeSerials(defaultBaudRate);
  initializeRN2483(RN2483_power_port, reset_port);
  pinMode(led_port, OUTPUT); // Initialize LED port  
  dht.begin();
  blinky();
}

void loop() {
    float h = dht.readHumidity();
    float t = dht.readTemperature();

    // check if returns are valid, if they are NaN (not a number) then something went wrong!
    if (isnan(t) || isnan(h)) 
    {
        Serial.println("Failed to read from DHT");
    } 
    else 
    {
        Serial.print("Humidity: "); 
        Serial.print(h);
        Serial.print(" %\t");
        Serial.print("Temperature: "); 
        Serial.print(t);
        Serial.println(" *C");
    }
  int temp = (int) t;
  int hum = (int) h;  
  int tempdec = t * 100;
  int humdec = h * 100;

// Uncomment the line below for what you want to send

  send_LoRa_data(set_port, String(temp) + "F" + String(hum));      //send temp / hum as rounded int over lora
  //send_LoRa_data(set_port, String(tempdec) + "F" + String(humdec)); //send temp / hum as 4 digit integer (decimals included)

  blinky();
  delay(1000);
  read_data_from_LoRa_Mod();
  delay(30000);
}

void InitializeSerials(int baudrate)
{
  delay(1000);
  print_to_console("Serial ports initialised");
}

void initializeRN2483(int pwr_port, int rst_port)
{
  //Enable power to the RN2483
  pinMode(pwr_port, OUTPUT);
  digitalWrite(pwr_port, HIGH);
  print_to_console("RN2483 Powered up");
  delay(1000);
  
  //Disable reset pin
  pinMode(rst_port, OUTPUT);
  digitalWrite(rst_port, HIGH);

  //Configure LoRa module
  send_LoRa_Command("sys reset");
  read_data_from_LoRa_Mod();

  send_LoRa_Command("radio set crc off");
  delay(1000);
  read_data_from_LoRa_Mod();

  send_LoRa_Command("mac set nwkskey " + set_nwkskey);
  read_data_from_LoRa_Mod();

  send_LoRa_Command("mac set appskey " + set_appskey);
  read_data_from_LoRa_Mod();

  send_LoRa_Command("mac set devaddr " + set_devaddr);
  read_data_from_LoRa_Mod();

  //For this commands some extra delay is needed.
  send_LoRa_Command("mac set adr on");
  delay(1000);
  read_data_from_LoRa_Mod();

  send_LoRa_Command("mac save");
  delay(1000);
  read_data_from_LoRa_Mod();

  send_LoRa_Command("mac join abp");
  delay(1000);
  read_data_from_LoRa_Mod();

}

void print_to_console(String message)
{
  Serial.println(message);
}

void read_data_from_LoRa_Mod()
{
  if (Serial1.available()) {
    String inByte = Serial1.readString();
    Serial.println(inByte);
  }

}

void send_LoRa_Command(String cmd)
{
  print_to_console("Now sending: " + cmd);
  Serial1.println(cmd);
  delay(500);
}

void send_LoRa_data(int tx_port, String rawdata)
{
  send_LoRa_Command("mac tx uncnf " + String(tx_port) + String(" ") + rawdata);
}


void blinky()
{
  digitalWrite(led_port, HIGH);   // turn the LED on (HIGH is the voltage level)
  delay(500);                     // wait for a second
  digitalWrite(led_port, LOW);    // turn the LED off by making the voltage LOW
  delay(500);                     // wait for a second
  digitalWrite(led_port, HIGH);   // turn the LED on (HIGH is the voltage level)
  delay(500);                     // wait for a second
  digitalWrite(led_port, LOW);    // turn the LED off by making the voltage LOW
  delay(500);                     // wait for a second

}

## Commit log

2016-07-08 Basic controls of IoT Academy Marvin LoRa Development board
    This version supports:
    - Sending LoRa uplink messages using ABP
    - Blink three times when sending data
2016-07-14 Added comments and support for powering on/off
2016-07-14 Added Powering up Marvin
2016-08-14 Adding eagle layout
    board and schematic
    [Marvin_0.5.2.brd, Marvin_0.5.2.sch]
2016-08-14 brd updates
    [Marvin_0.5.2.brd, Marvin_0.5.2.sch]
2016-09-04 Update MarvinBase.ino
    Some minor changes.
    -Using led_port instead of hardcoded 13.
    -Using declared defaultBaudRate, also changed to long.
    -Changed order in function: initializeRN2483, order was sys,mac radio. Now: sys, radio, mac
    -Description of set_port changed
2016-09-09 Added folders to enable running from Arduino IDE directly
2016-10-30 cleaning up pcb
    [Marvin_0.5.2.brd, Marvin_0.5.2.sch]
2017-03-14 Added sensor read
    Read float value, cast to int and send in string as lorapayload
2017-03-27 Update documentation
    Updated documentation for pin selection and sending temperature value as
    integer or multiplied
2017-03-27 Added link to seeed wiki
    Link to seeedstudio wiki page for grove temperature v1.2
2017-03-27 Added arduino file for Temp+humid sensor from Grove
    You have to download the dht library from
    http://wiki.seeed.cc/Grove-Temperature_and_Humidity_Sensor_Pro/
2017-03-27 Added link to seeedstudio github for library temp&humid sensor
2017-03-27 Fixed error temp sent twice + added delimiter
    The temperature was sent twice, fixed so temp and humidity are being sent.
    Also added delimiter between te two values, because, although humidity usually is 2 digits, it is better not to rely on that.
    Since the delimiter had to be an acceptable HEX value I choose "F"
    [MarvinBase_temp_humid_sensor.ino]
2017-03-28 Changed lora message
    send temperature / humidity rounded
    or send temp / hum as 4 digit
2017-06-09 Added Hackaton Ino File
    Setting Cayenne low power payload
2017-06-10 Remove abp folder due to sync issues
    [Marvin_ABP_CayenneLPP.ino]
2017-06-24 update temperature humidity code

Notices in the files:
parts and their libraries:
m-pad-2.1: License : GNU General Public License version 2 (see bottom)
